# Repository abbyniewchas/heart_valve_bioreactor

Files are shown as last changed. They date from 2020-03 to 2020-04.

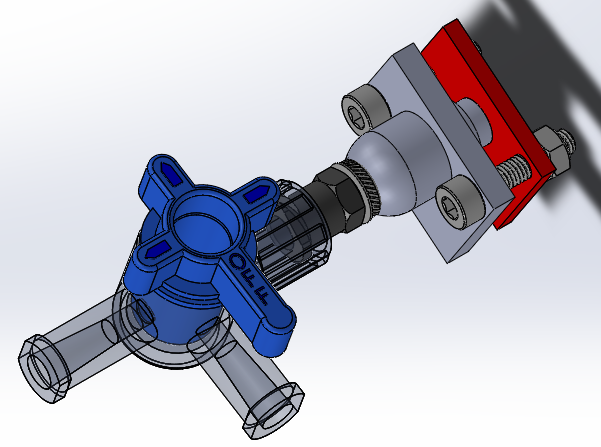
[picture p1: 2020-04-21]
designs/Pressure transducer /PressureSensorv2/Assem2.PNG

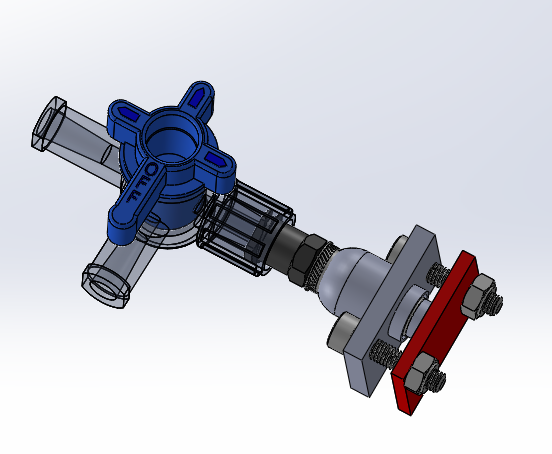
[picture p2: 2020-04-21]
designs/Pressure transducer /PressureSensorv2/Assem1.PNG

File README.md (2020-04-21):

# heart_valve_bioreactor
This github repo contains the CAD and software for our capstone's bioreactor

# Designs
The CAD for all designed components are included in this folder. Details of how to adjust the processing chamber's parameters are given in our group's capstone design report (CDR).

# Software
The software has been broken up into Arduino code and MATLAB code. The Arduino code is what runs on our system's arduino in order to run the bioreactor. The only file that should be changed in this folder is the .ino file that is actually flashed onto the Arduino board. The MATLAB folder contains files for data analysis and as well as code and simulink models that are useful for control design.

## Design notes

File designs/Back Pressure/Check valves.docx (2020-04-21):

Check valves

We need a check valve to ensure the fluid in the diaphragm pump can only exit one direction. The ideal check valve in this situation would be one with zero cracking pressure. This would mean that only a few cm of H2O would open the valve, allowing for continuous flow from the media reservoir into the diaphragm. The ideal check valve would also have zero closing pressure, so that upon contraction of the diaphragm the valve immediately closes. There are several different types of check valves, but there are three worth considering for this application.

- Swing valves
- Ball valves
- Poppet valves

These three types of valves tend to have the lowest cracking pressure available. Through research, several potential vendors were identified. The vendor CheckAll was chosen, as they produce valves with cracking pressure of 0.125psi, the lowest that could be found at a reasonable price. They also allow tunable materials so that the valve could be customized to our system.

https://www.checkall.com/PDFfiles/U3.pdf

https://www.checkall.com/PDFfiles/application_guidelines.pdf

Sizing

Going back to Cv, we want a valve that can allow for at least 5 L/min at as low of a pressure as possible. This will allow us to limit the necessary elevation of the media reservoir. CheckAll makes valves in multiple sizes, and the two that are most applicable are the ½” and ¾” sizes. These valves have Cv of 4.3 and 7.2 respectively.

Cv 4.3

Using the Cv equation, in order to get 5 L/min across this valve we would need a dP of 0.3psi or 21.6 cm H2O.

Cv 7.2

Repeating the same calculation, we would need a dP of 0.183psi or 12.9 cmH2O

These calculations lend that it would be best to go with a ¾” valve so that it is not necessary to elevate the media reservoir by nearly 22cm.

Housing Material

The three most common materials for valves are carbon steel, brass, and stainless steel. For our purposes, stainless steel is the obvious choice. Carbon steel is prone to rusting in aqueous environments, and brass’s lead content disqualifies it from use with potable water which is a solid reason not to be using it for allowing cell growth.

Seat Material

Two of the most common seat materials are BUNA-N and EDPM. BUNA is better suited for corrosive medias, oils, and hydrocarbons. EDPM is made specifically for water systems, making it the obvious choice.

½” 99.55

¾” 127.90

1” 179.15

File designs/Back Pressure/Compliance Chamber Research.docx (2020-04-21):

Rough material requirements:

1. Can withstand pressures of up to 180mmHg (3.5psi)
  - Depending on how we make the chamber this requirement will be more focused on the seams/fittings and glued surfaces rather than the material itself. Most hard plastics will withstand this pressure easily
2. Biocompatible
3. Compatible with EtO
  - https://www.industrialspec.com/resources/plastics-sterilization-compatibility/
    - Good table of different plastics and their compatibility with different sterilization methods
4. Clear (allows for visual inspection of function, accurate adjustment of volumes)
5. Reasonable price (compliance chamber should not be $1000)
  - Easily machinable or stock cylinder source would be best

Candidates:

- Acrylic/PMMA
  - https://www.ipolymer.com/pdf/Acrylic.pdf
  - https://www.acmeplastics.com/acrylic-vs-polycarbonate
  - https://www.vanderveerplastics.com/compare-materials.html?sel1=acrylic&sel2=polycarbonate
- Polycarbonate
  - https://www.ipolymer.com/pdf/Polycarbonate.pdf
  - https://www.mddionline.com/medical-applications-polycarbonate
    - Polycarb is a popular material in medicine, used in many devices and tubing
    - Stronger than acrylic, but less transparent (only slightly)
    - More expensive
    - Easier to machine (would only really make a difference if we machine it ourselves, acrylic is stiffer → easier to shatter during the machining process)

Polycarb seems to be the better fit, but either will work for our purposes

Volume Requirement

See derivation PDF

Pressure Requirement

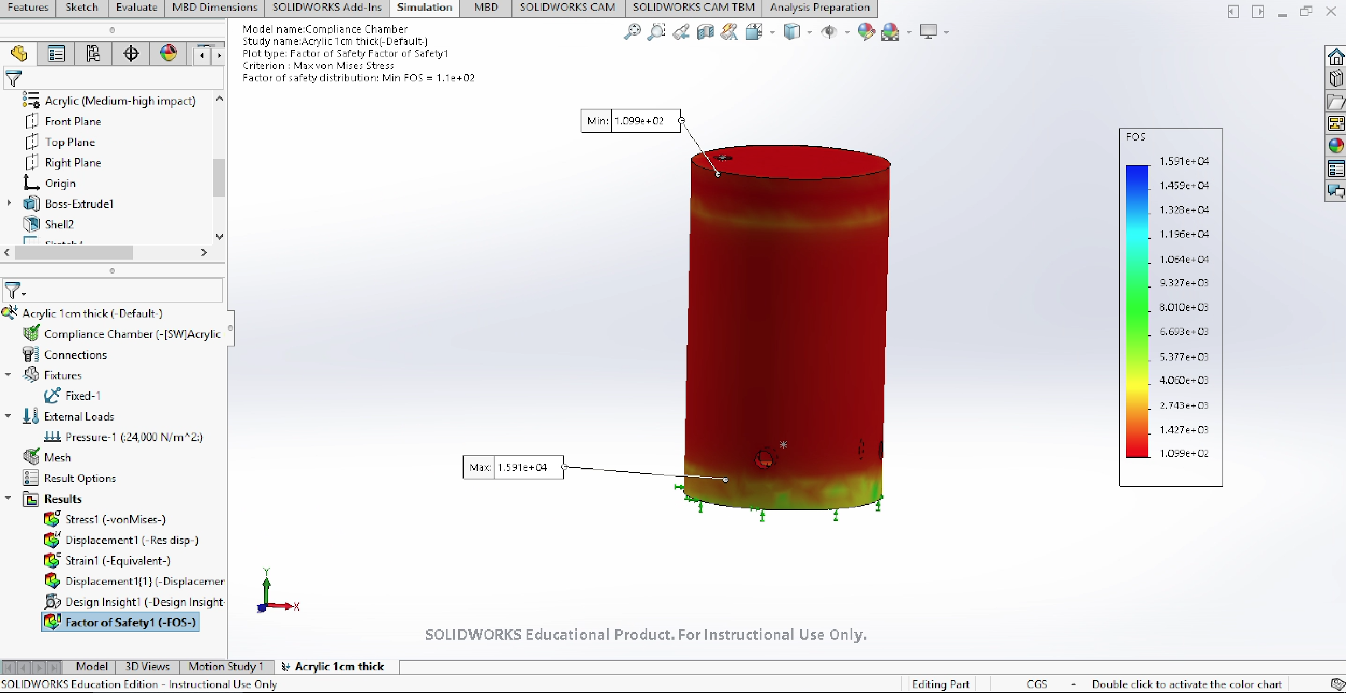
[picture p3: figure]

Solidworks simulation shows that with 1cm thick walls of Acrylic (PMMA) our factor of safety at 180mmHg would be over 100 → this is more than safe. Polycarbonate is a stronger material so this design would work for either material.

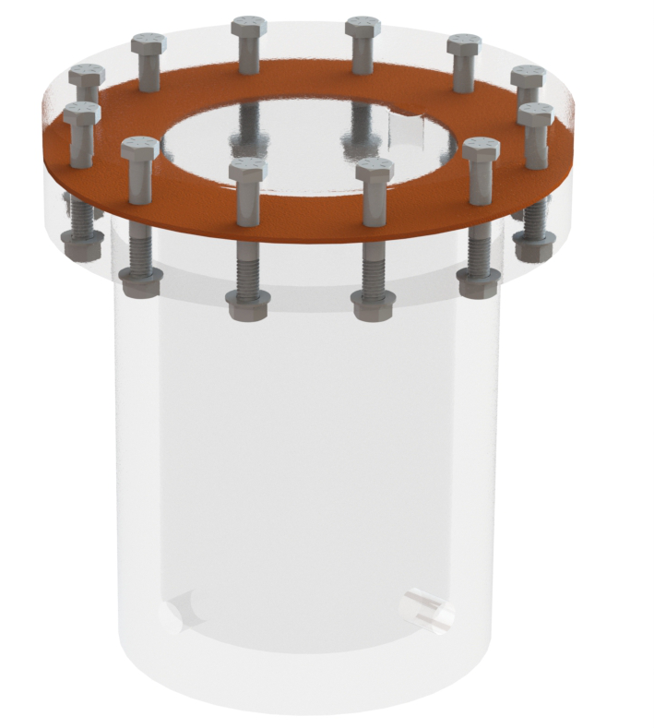
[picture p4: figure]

Next Steps

The only remaining unknown for the compliance chamber is the inlet/outlet hole sizes. These will hopefully be known soon as we decide on fitting types and tubing sizes. Finally, we need to look into designing the chamber so that it is manufacturable. The design to the right is a first pass concept featuring a machined cylinder with a flange that is sealed by a cap / rubber disk fastened with screws. While this design would work, the big cylinder/flange piece is not very manufacturable

Design update:

Having a three way valve connected to a single inlet on the bottom of the compliance chamber would be the way to go.

Manufacturing

Contracting

- Most straightforward choice of manufacturing method is CNC. Plenty of companies do CNC machining in both acrylic and polycarbonate
- One quote was fucking 3500$$$
- Need to modify the current design if we are going to contract it
  - Large cylinder piece with the flange is not very manufacturable. CNC starts with a block of material, machining that cylinder means a ton of material is needed

Stock acrylic + acrylic cement

- Can change design to just a cylinder with two caps, buy stock acrylic from mcmaster
  - https://www.mcmaster.com/acrylic
- Probably use some type of resin to join them
  - Weld-on 4
  - https://www.gogsg.com/ASSETS/DOCUMENTS/ITEMS/EN/ips4-04_spec.pdf
- Drill holes and tap them ourselves where necessary
- Maybe 200$, leaves room for messing up

Dimensions + links for parts we would order to build it

Systemic

  - 4” ID, 5.82 - 6” height
  - ~~8486K575~~ (https://www.mcmaster.com/8486K575) ~~main walls~~
  - ~~1221T95~~ (https://www.mcmaster.com/1221T95) ~~bottom disc~~
  - ~~1221T39~~ (https://www.mcmaster.com/1221T39) ~~2x Top discs~~
- Pulmonary
  - 5” ID, 8.75-9.32” height
  - 8486K585 (https://www.mcmaster.com/8486K585) main walls
  - 8581K37 (https://www.mcmaster.com/8581K37) bottom disc
  - ~~https://www.mcmaster.com/8581K39~~ ~~2x Top discs~~
- For the top and bottom / flange components, you would get a cast acrylic SHEET and just laser cut it. Noah has a ton of acrylic stock we can use so don’t buy yet
- Weld-on 4
  - https://www.amazon.com/Weldon-Applicator-Bottle-Pint-10308/dp/B00TCUJ7A8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
  - https://www.gogsg.com/ASSETS/DOCUMENTS/ITEMS/EN/ips4-04_spec.pdf
  - https://www.gogsg.com/ASSETS/DOCUMENTS/ITEMS/EN/IPS4-01_MSDS.pdf

Blown glass?

- nah

Pressure Release Valve

- Should release pressure once pressure in compliance chamber exceeds 3.5 psi
- Possible products
  - 4703K54 (https://www.mcmaster.com/4703K54)
  - 48935K25 (https://www.mcmaster.com/48935K25) (cheapest, smallest)
  - 7844K52 (https://www.mcmaster.com/7844K52)

O-Rings

Literature

- Parker O-Ring Handbook (https://www.parker.com/Literature/O-Ring%20Division%20Literature/ORD%205700.pdf)
  - Groove dimensions for a face seal:page 4-18
  - Compression force required: Figures 2-4 through 2-8 in Section II

Products

- https://www.mcmaster.com/o-rings
- #254 should work 9452K355 (https://www.mcmaster.com/9452K355)
- Also 161
  - .077 +/- .003” depth X 0.122 +/- .002” width
- 51
  - .052 +/- .002” depth X .086 +/- .002” width

Manufacturing feedback from Noah

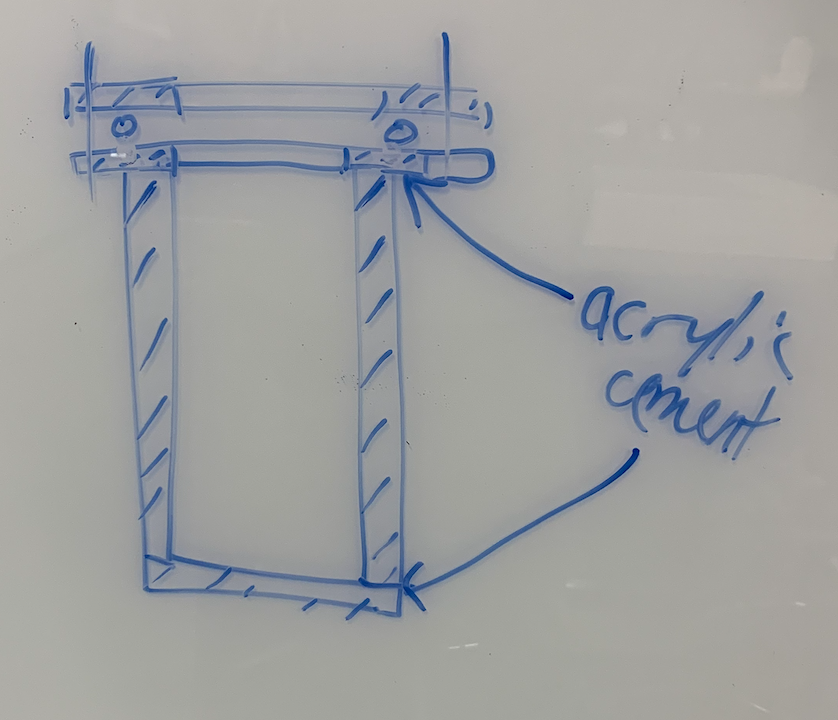
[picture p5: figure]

Design 1

- For the top and bottoms, get CAST acrylic SHEETS
- Cast acrylic is easier to machine, laser cutting works on either cast or extruded
- For the O-ring groove you would use laser cutting and engrave it. Would take some trial and error to get the correct specs for the O-ring
- Profile of flange + screw holes are easy to laser cut

Design 2

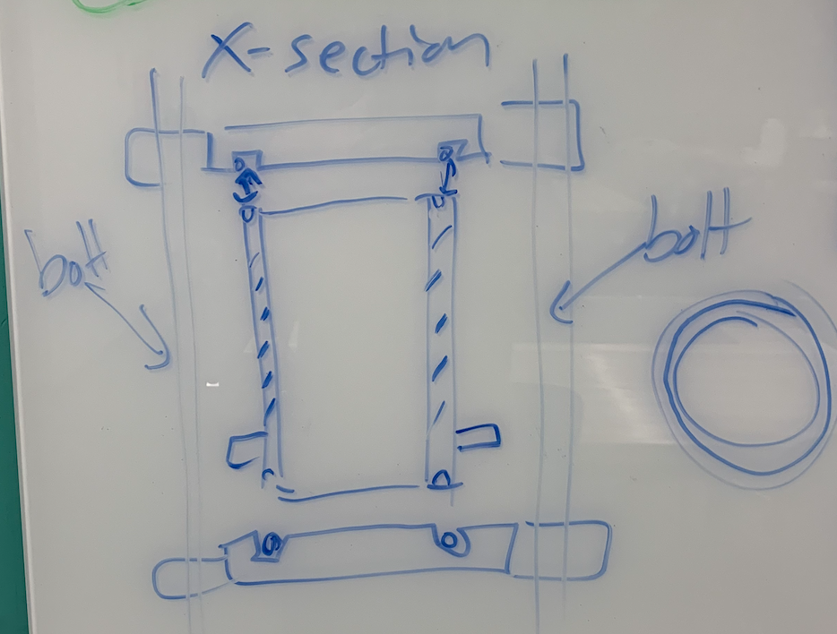
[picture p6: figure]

- I asked noah if he could put a groove on the top and bottom of the tube itself if the tube was thick enough
  - He said with a lathe it is doable

Confirmed redesign:

- Top and bottom pieces
  - Cast acrylic sheet
    - 8560K266 (https://www.mcmaster.com/8560K266)
  - One inlet each
  - O-ring groove on each
    - O ring dimensions must match with tubing dimensions such that the tube edges form one face of the seal
    - 9557K142 (https://www.mcmaster.com/9557K142)
      - EPDM
- Walls
  - 8486K585 (https://www.mcmaster.com/8486K585) main walls
- RODS
  - 10” long, ¼”-20 stainless steel 316
  - McMaster: https://www.mcmaster.com/90575A224
- Cutter for machining as requested by Noah
  - https://www.sparkfun.com/products/14853
- Waste board for machining as requested by Noah
  - https://www.sparkfun.com/products/14904

Other cost-effective tank designs

https://www.usplastic.com/catalog/item.aspx?itemid=134241&catid=835

Notes:

EDPM is biocompatible, has excellent swell resistance, therefore we select the smaller gas and vacuum groove width from the o-ring handbook.

Delrin is biocompatible

‘

Material compatibility charts for funsies: https://www.calpaclab.com/acetal-polyoxymethylene-chemical-compatibility-chart/#

Info about durometer:

https://promo.parker.com/promotionsite/oring-ehandbook/us/en/ehome/Hardness

Info about EDPM being used in medical applications: https://www.aceseal.com/o-ring-materials

Biocompatibility of delrin: https://onlinelibrary.wiley.com/doi/abs/10.1002/jbm.820190505

List of biocompatible plastics: https://www.google.com/imgres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 (https://www.google.com/imgres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)

Fittings:

Bottom T-connector: ½” NPT, ½” pipe diameter, barb, made out of acetal (same as Delrin)

https://www.mcmaster.com/5047K61

Top T-connector:

Nuts:

¼”-20 Flange nut: https://www.mcmaster.com/94842A101

¼”-20 Cap nut: https://www.mcmaster.com/98858A101

Male Luer-Male ¼” NPT adapter: https://www.mcmaster.com/51525K437

½” NPT Stopcock: https://www.mcmaster.com/4793K844

TO DO:

1. Determine fittings for pressure relief and stopcock at the top of the compliance chamber
2. Determine torque spec and buy torque wrench
3. Pat ourselves on the back
4. Have a pint

Torque Specification

Directions: https://www.darcoid.com/userfiles/cms/subpage/files/31/Installation.pdf

Part 1: Calculate compressive load required for face seal o-ring application

https://www.parker.com/literature/O-Ring%20Division%20Literature/O-Ring%20ehandbook%20pdfs/compression%20load%20force%20by%20cross%20section%2070%20and%2090%20duro.p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

Squeeze is 19-32%, the midpoint is ~25%

This is the ratio of deformation to the thickness of the o-ring.

Referring to the chart above, 25% squeeze results in 25 lbs per inch of o-ring circumference of compressive load.

Part 2: Calculate necessary bolt torque and spacing for the face seal

https://mechanicalc.com/reference/bolted-joint-analysis

1. STOPCOCK/PRESSURE RELIEF FITTINGS

Sterile Pressure Relief

→ NPT to Female Luer Adapter: (https://www.mcmaster.com/51525K437)https://www.mcmaster.com/51525K437

→ Luer Male to Luer Female On/Off Valve: (https://www.mcmaster.com/7033t24)https://www.mcmaster.com/7033t24

→ Male Luer Filter: Sterifix 0.2 μm; B. Braun Melsungen AG, Germany (we already have these)

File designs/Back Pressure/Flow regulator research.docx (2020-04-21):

[1]https://www.cedengineering.com/userfiles/Control%20Valves%20Basics%20-%20Sizing%20&%20Selection.pdf

Ball Valves

- high recovery valves, having a low pressure drop and relatively high flow capacity.
- Usually open or closed, limited throttling
  - Not what we want

Butterfly Valves

- Minimal pressure drop when fully open (good for us)
- Limited throttling

Globe Valves

- Precise flow regulation, but design introduces lots of turbulence to flow even when fully open
  - This means an open valve would still have a decent amount of resistance
- Wide throttling
- Needle valves are in this category

Gate Valves

- Best for open/closed
- Best for infrequent operation, good sealing

Types of actuators:

Pneumatic, electronic, manual

- Electronic has superior precision, fastest response time
- Mechanical has same range of regulation but with much longer timescale of adjustment (also much cheaper)

Types of regulators:

- Fixed orifice flow regulators
  - needle/globe valve, select a constant orifice size
- Pressure compensating flow regulators
  - Include a spring to retain constant flow rate despite pressure changes

General guidelines: Valves should be sized so that maximum flow is obtained at about 90% valve open. Valves should be able to provide normal flow conditions at around 60% to 70% of the travel. Valve should provide minimum flow when about 10% open [1].

Flow Coefficient Cv:

- Cv = amount of flow in gpm that will flow through the valve when it is 100% open with a pressure differential of 1 psi (S is specific gravity, which is 1 for our purposes)
  - Our max pressure differential across the valve is going to be 180mmhg (3.5psi) according to our requirements, but typically it will be 120 (2.3psi)
  - Our max flow will be around 5L/min = 1.32gpm
  - So we want at a pressure difference of 2.3psi across an open regulator to allow 1.32gpm of flow
    - Cv = 1.32gpm / sqrt(2.3psi) = 0.87
  - But really pulmonary pressures are the limiting case. Cv of 0.87 → no way we will get 5L/min at a pressure drop of 20mmHg across the regulator.
    - We need 5 L/min with 20mmHg (.38psi) drop across the valve
    - Cv = 1.32gpm / sqrt(.38psi) = 2.14
    - We want normal flow (5L/min) when the valve is ~60% open, so a Cv closer to 3 would probably be fine

https://www.globalspec.com/industrial-directory/electronic_air_flow_control_valve#articles

Viable Options
Mechanical | https://www.mcmaster.com/45585k78 (Cv = 2.67) - can connect to tubing of ¾” OD https://www.mcmaster.com/1042k21 (Cv = 2.47) 1042K36 (https://www.mcmaster.com/1042K36)
Electronic | https://www.omega.com/en-us/valves-pumps-and-mixers/valves/proportional-valves/pv14/p/PV12-B (Cv = 3.5)

How necessary is an automatic valve?

- Main purpose: augment the function of the pump to have finer control over pressure waveform
  - It would primarily augment the pressure curve after the pump “contraction” is finished, assuming the pump is capable of generating the initial curve

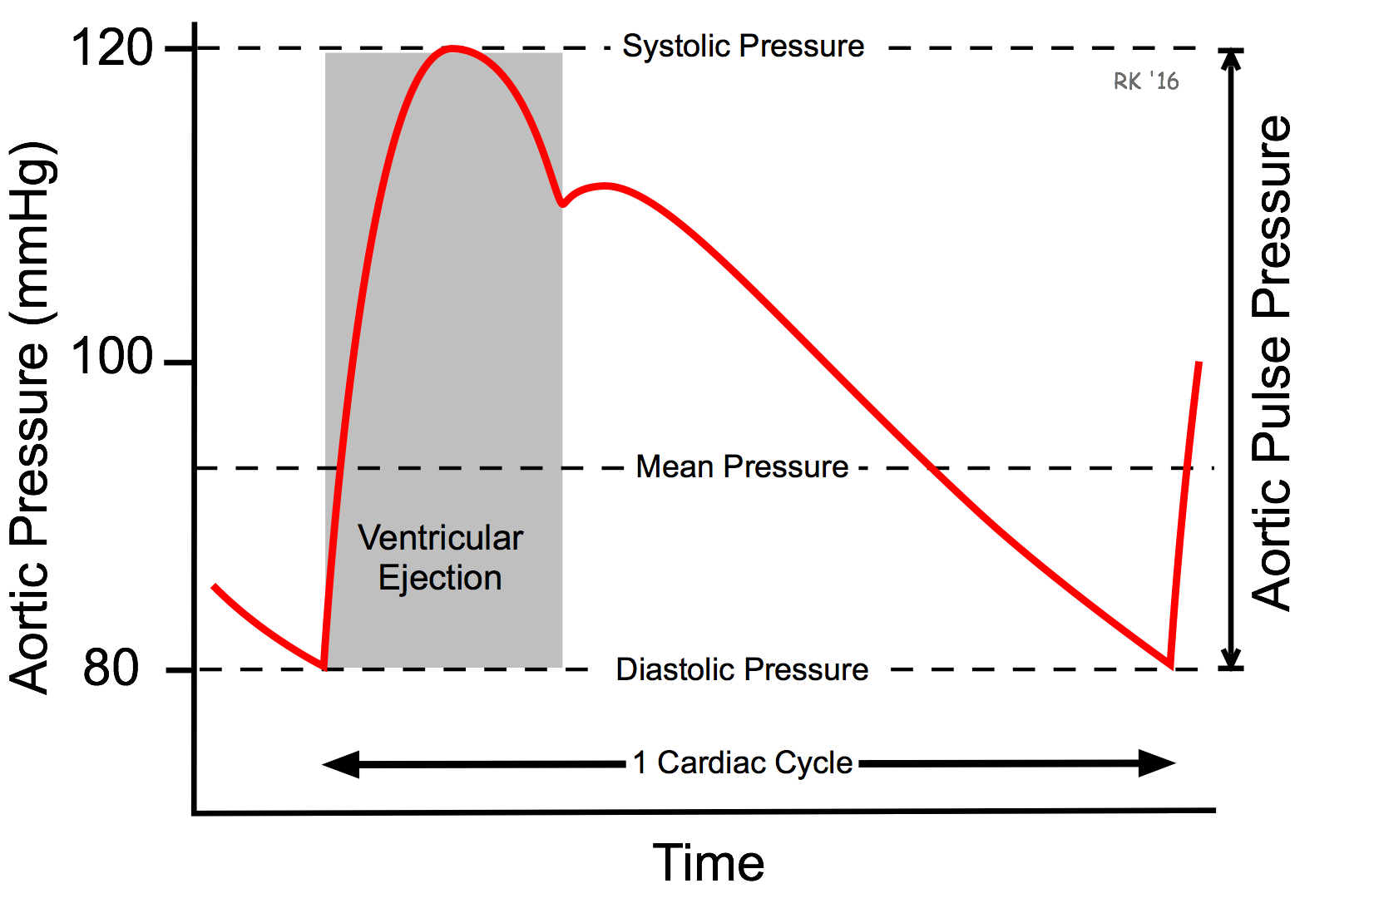
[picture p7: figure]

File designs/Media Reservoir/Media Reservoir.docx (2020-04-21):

Media Reservoir

Components

Filter

- The aortic chamber fluid outlets were connected by silicone tubing to an air-tight pressurizing reservoir (compliance chamber), which in turn was connected to a second reservoir exposed to atmospheric air via one top outlet fitted with a 0.22 μm air filter. (https://www.ncbi.nlm.nih.gov/pmc/articles/PMC3039844/#!po=12.5000)
- Sterile filters (Sterifix 0.2 μm; B. Braun Melsungen AG, Germany) were interposed at the top of the medium reservoir to avoid contamination during oxygenation of the circulating medium. (https://pdfs.semanticscholar.org/cb62/8044a4c4445836e1689b58cf9297ad36c74d.pdf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)
- 0.22 vs 0.45 https://journal.pda.org/content/50/3/147

Container

- Volume? Calculate…
- Material? Sterilizable, biocompatible, hemocompatible

Emptying

- Luer lock port
- To stop-cock
- To removal sterile luer lock filter

All ports need to be sterile, mixing (inlet from top? - research mixing and gas perfusion), find a paper for mixing necessity for gas perfusion in mammalian cells (specifically heart valves)

Fittings

Media Reservoir Media Exchange Ports

→ ¼” NPT to Luer socket (https://www.mcmaster.com/9198T18)https://www.mcmaster.com/9198T18

→ ¼” Luer plug to barb (https://www.mcmaster.com/9198T16)https://www.mcmaster.com/9198T16

Ø One line goes to the system

Ø Switch the lines to add media

Ø Don’t connect a media bag at the other end and it will drain.

Ø Also could use Luer Male to Luer Female On/Off Valve with an in-line luer filter: (https://www.mcmaster.com/7033t24)https://www.mcmaster.com/7033t24

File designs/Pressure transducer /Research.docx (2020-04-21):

https://www.reddit.com/r/arduino/comments/67x9zy/4wire_pressure_transducer_wiring/

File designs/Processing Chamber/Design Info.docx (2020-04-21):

Machining top and bottom piece:

-Protolabs SLA 3D printer

-Watershed material that will be custom finished to be clear

-Prints with a tolerance of 0.05mm

https://www.designworldonline.com/biocompatible-material-fits-medical-design-requirements/

https://www.fostercomp.com/stewardship/usp-class-vi/

Application of Watershed:

WaterShed XC 11122 offers many properties that mimic traditional engineering plastics including ABS and PBT. This makes the material ideal for many applications in the automotive, medical and consumer electronics markets and include:

- Lenses

- Packaging

- Water flow analysis

Fittings:

-CHECK TAPS

Screws/Bolts:

-3in long, ¼ by 20 threading

https://www.mcmaster.com/85555a113

https://www.mcmaster.com/95462a029

https://www.mcmaster.com/92196a801

O-rings:

-O-ring EPDM 029

Aortic Root Info:

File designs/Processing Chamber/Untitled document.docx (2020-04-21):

How to Update Processing Chamber SolidWorks Files

The processing chamber will need to be updated to reflect the dimensions of the hydrogel heart valve. The current model is for the mechanical heart valve that was being tested.

1. Top of the Processing Chamber
  1.1. The first important thing to note is that 10 different SolidWorks files were created for valves ranging from 10-30mm in increments of 2mm. The file name doesn’t necessarily correlate with the same size of the valve that is being created. For instance, the title “TopChamber_24mm” refers to the opening diameter of the aortic root. This diameter is actually the outer diameter of where the leaflets are inserted, highlighted in Figure 1 as “Outer Leaflet Diameter”. This will change depending on the dimensions of the heart valve.

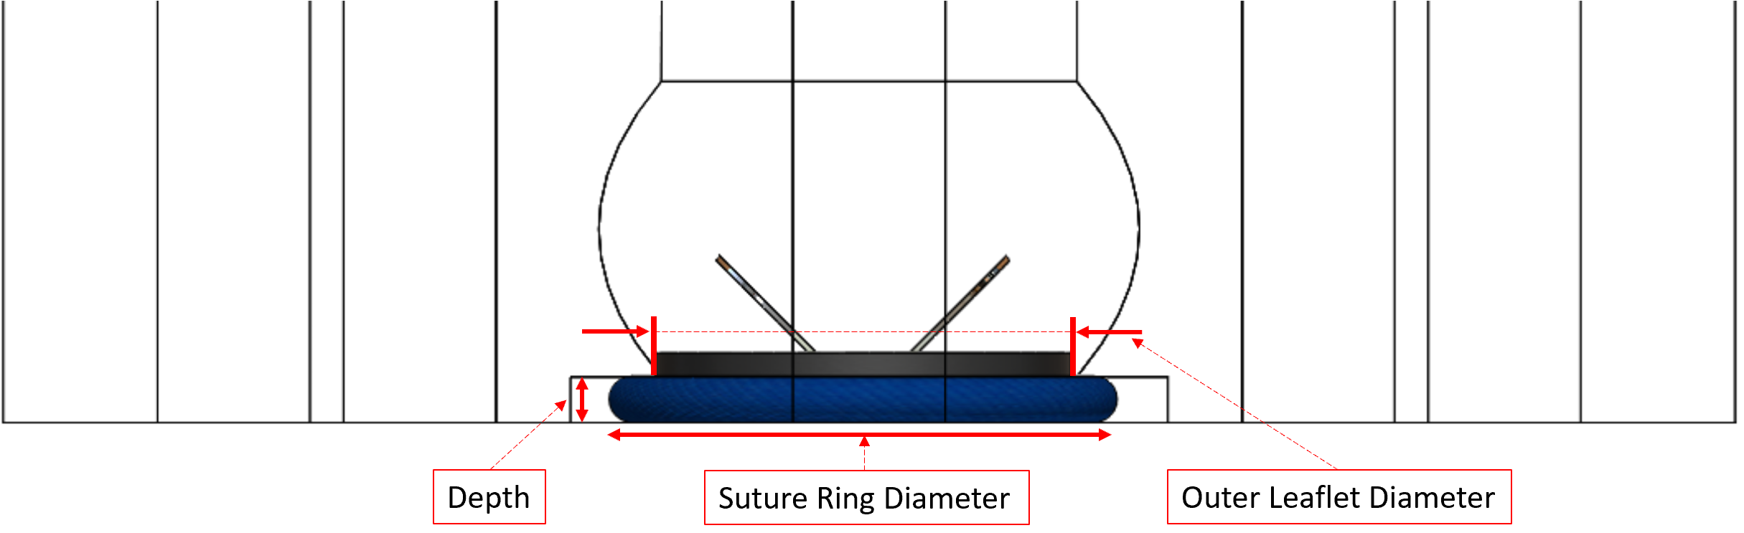
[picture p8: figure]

Figure 1

  1.2. The mechanical valve that we were given was a size 22. It had an inner diameter of 20mm, an outer leaflet diameter of 24mm, an outer suture ring compression diameter of about 32mm and a suture ring depth of 3.15mm. The heart valve is clamped in place by the suture ring. The dimensions are shown below.

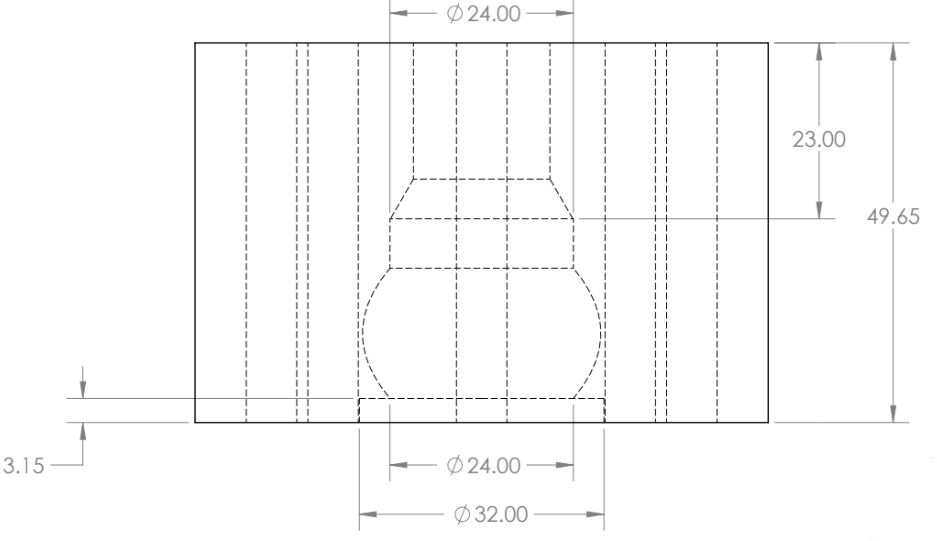
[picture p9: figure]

Figure 2

  1.3. The dimensions will need to be edited in the SolidWorks tree.The SolidWorks tree is shown in Figure 3. The key dimensions are the “Outer Leaflet Diameter” and “Depth”. Most likely, the NPT Hole, Aortic Root, Ascending Aorta, and Bolts Holes will not need to be changed, as they do not specifically hold the heart valve in place.

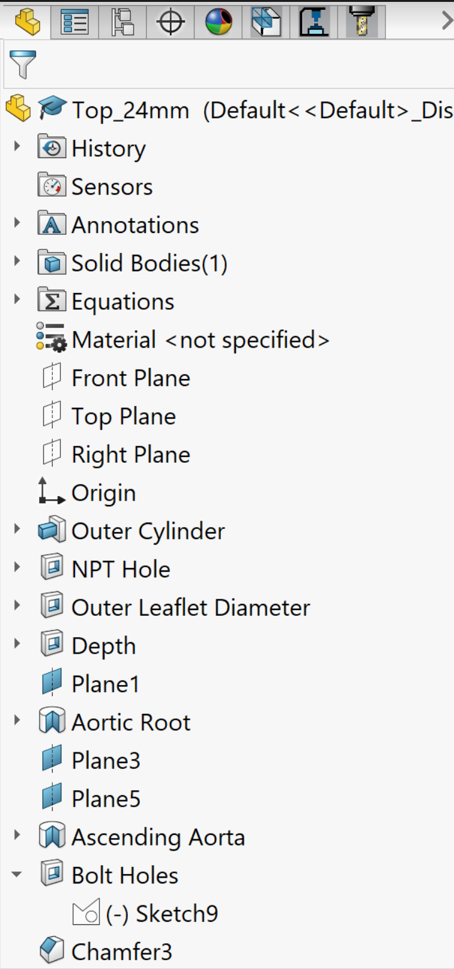
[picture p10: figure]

Figure 3

  1.4. One of the dimensions that will most likely need to be changed is the diameter of the outer leaflet diameter. As mentioned earlier, the SolidWorks file is named in reference to this diameter. The Top_24mm means that the outer leaflet diameter is 24mm. All of the aortic root dimensions are tied to the outer leaflet diameter through equations, shown in Figure 4. The equations are shown in Figure 4. The aortic root opening is the same diameter as the outer leaflet diameter “A”; in the SolidWorks model this is shown as “D2@Sketch6” and the equation is A/2, because it is a cut revolve so only half of the outline was drawn and then revolved around the centerline.. The diameter where the aortic root opens into the ascending aorta is also the same diameter as “A”; in the SolidWorks model this is shown as “D3@Sketch” and the equation is A/2, because it is a cut revolve so only half of the outline was drawn and then revolved around the centerline. The height of the aortic root .71x the outer leaflet diameter size “A”, and is called “Aortic Root Height” in global variables. The maximum diameter of the aortic root occurs at half the aortic root height and is called “Max Diameter Height” in global variables. The maximum diameter of the aortic root is 1.3x larger than the outer leaflet diameter and is shown as “Max Diameter” in the global variables; to reiterate the aortic root was created using a revolve cut which is why the equation shows A*0.65 (half of 1.3). Every time the outer leaflet diameter is adjusted, these values automatically adjust with it.

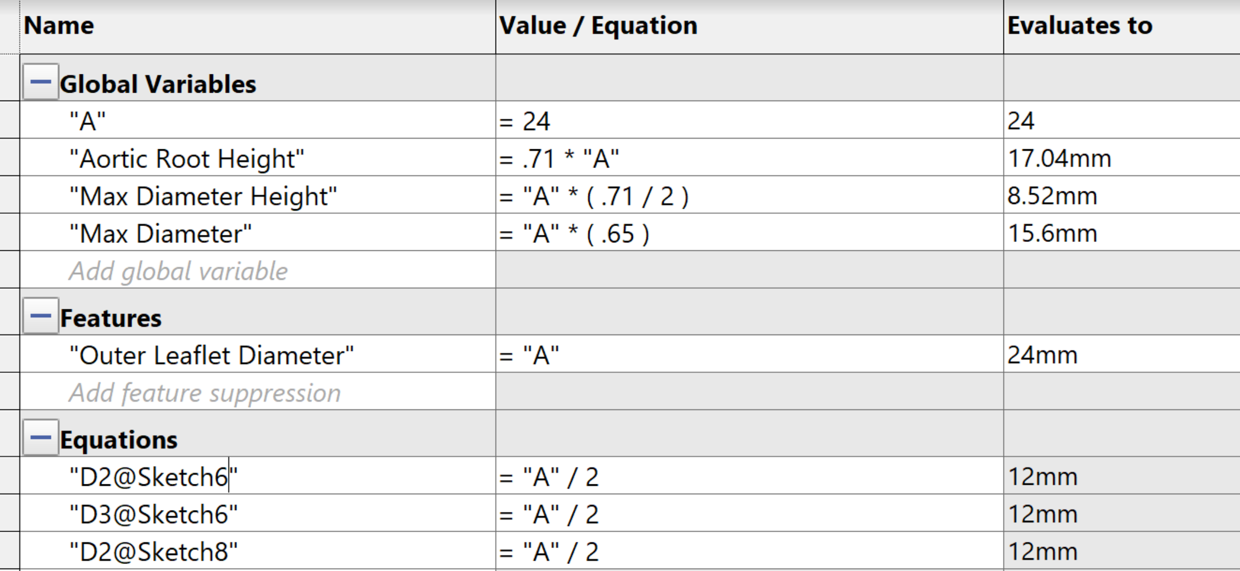
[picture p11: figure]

Figure 4: Aortic Root Equations

  1.5. For the hydrogel heart valve, the dimensions for holding it in place will need to be changed. The rigid ring of the valve needs to be held firmly in place throughout testing. To ensure this happens the cut extrude of depth will need to be changed to match whatever the depth of the suture ring being used is. Also, the diameter of the depth will need to be changed to ensure it is wider than the width of the compressed suture ring. In our SolidWorks model an extra 2mm was added to this depth diameter, to ensure that the fabric on the ring will not be clamped outside of its designated cutout. Lastly, the outer leaflet diameter will have to be adjusted to whatever the diameter is of the portion of the valve extruding into the aortic root.
2. Bottom of the Processing Chamber
  2.1. The bottom of the processing chamber is a cylinder with a flat face that mates with the top of the processing chamber to hold the heart valve in place. The two key dimensions of the bottom of the processing chamber are the inlet flow diameter and o-ring groove (Figure 5).

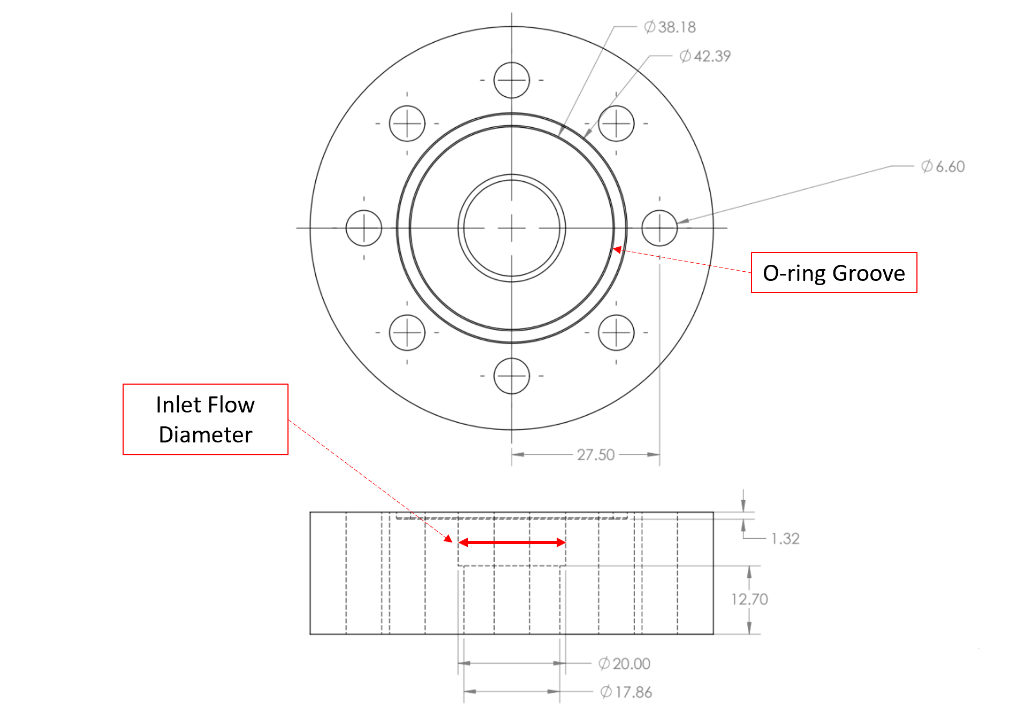
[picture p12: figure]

Figure 5: Bottom Chamber Diagram

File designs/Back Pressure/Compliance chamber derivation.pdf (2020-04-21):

The goal of this mathematical model is to derive the needed volume of the compliance chamber to accommodate physiological compliances. In other words, we want to know the total volume of air in the compliance chamber when there is only atmospheric pressure.

Compliance (C) is defined as a change in volume for a given change in pressure. In the physiological context, dV and dP will always be the same sign, as an increase in vascular pressure leads to an increase in volume of the vessel and vice versa. In our compliance chamber it is the opposite, as an increase in pressure results in a reduction of the volume of air in the chamber. As such there is a negative sign in the equation.

[1] C = −

∆V
∆P

wℎere ∆V = V2 − V1 and ∆P = P2 − P1

Additionally, we want to assume that there will be isothermal compression and expansion, which yields the second equation.

[2] V1P1 = V2P2

Rearranging equation [1] to solve for V2:

[3] V2 = V1 − C∆P

Substituting V2 from equation [3] into equation [2] and solving for V1:

V1 =

P2
P1

(V1 − C∆P)

V1 =

P2
P1

V1 −

P2
P1

C∆P

V1 (1 −

P2
P1

) = −

P2
P1

C∆P

V1 =

−

P2
P1

C∆P

(1 −

P2
P1

)

Multiply by -P1/-P1

V1 =

C∆P ∗ P2
P2 − P1
[4] V1 = C ∗ P2

The limiting case would be the case of highest compliance, as the air would be compressing the most for a given change in pressure. For this we use the pulmonary compliance value of
C = 2.6 ∗ 10⁻⁸ m5
N

i and
P2 = peak pulmonary pressure + atmospheric pressure = 20 mmhg + 760 mmHg = 780 mmHg = 103991.16 Pa

Plug into equation [4] to get

V1 = 2730 mL

Therefore, we need approximately 2.7 L of air in the compliance chamber for it to behave similarly to vessels in terms of the amount of back pressure it will generate for a given stroke volume. This value doesn’t need to be exact as we will also be able to control the pump and the fluidic resistor, but I believe this is a solid rationale for having the compliance chamber be in the realm of 2.7 L in size. Doing the same calculations with the minimum systemic compliance (systemic compliance is not always constant) yields a volume of approximately 1L. This would be accomplished by raising the water level in the compliance chamber until there is only ~1L of air.

Accounting for the fact that we will have fittings into and out of the compliance chamber which will always be submerged, the actual volume of the chamber will be closer to 3L.

i B. Knierbein, H. Reul, R. Eilers, M. Lange, R. Kaufmann, and G. Rau, “Compact mock loops of the systemic and pulmonary circulation for blood pump testing,” Int. J. Artif. Organs, vol. 15, no. 1, pp. 40–48, 1992.

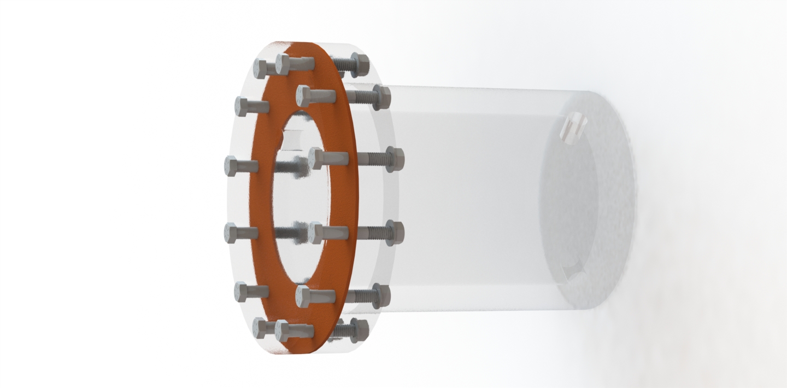
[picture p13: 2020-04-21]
designs/Back Pressure/Renders/Compliance chamber render.JPG

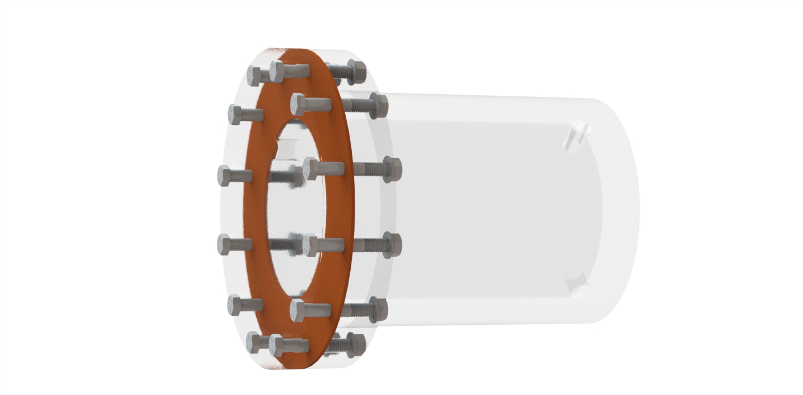
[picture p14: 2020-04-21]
designs/Back Pressure/Renders/Compliance chamber render 2.JPG

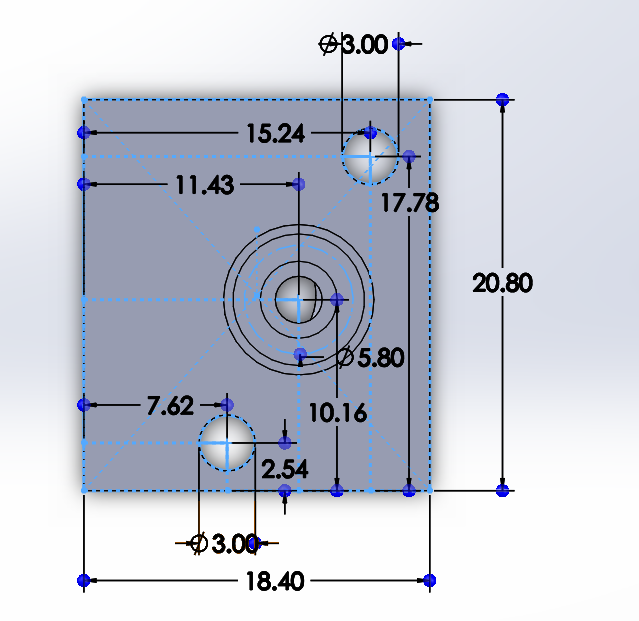
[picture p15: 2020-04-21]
designs/Pressure transducer /ForceSensorBoardDims.PNG

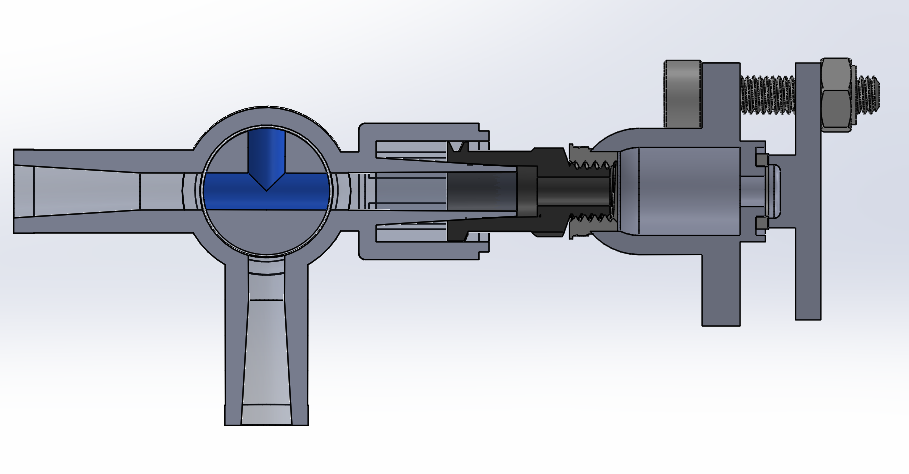
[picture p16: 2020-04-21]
designs/Full System CAD/Pressure Sensor V2/Assem3Split.PNG

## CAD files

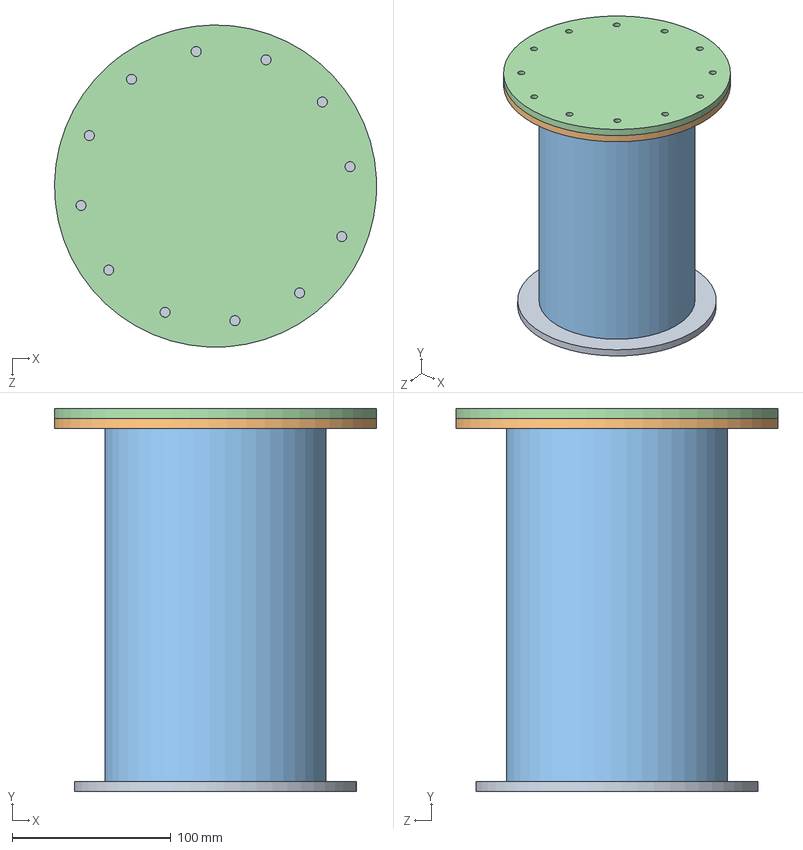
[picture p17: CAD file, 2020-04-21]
designs/Back Pressure/Solidworks/Compliance chamber assembly.SLDASM
203.1 x 241.6 x 203.1 mm
Bottom cap
Flange
Main body
Top Cap
McMaster O-RING #254

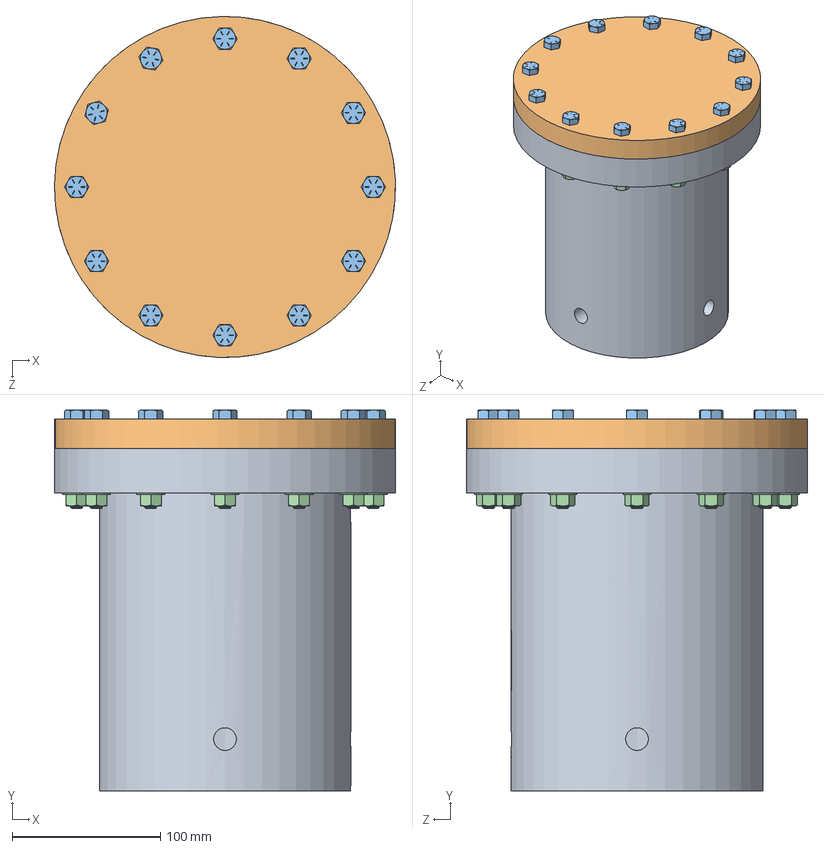
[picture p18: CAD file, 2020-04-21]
designs/Full System CAD/Compliance Chamber/Initial simulation mock-up/Compliance chamber assembled.SLDASM
230.0 x 256.9 x 230.0 mm
Compliance Chamber
Compliance Chamber Cap
screw x 12
nut x 12

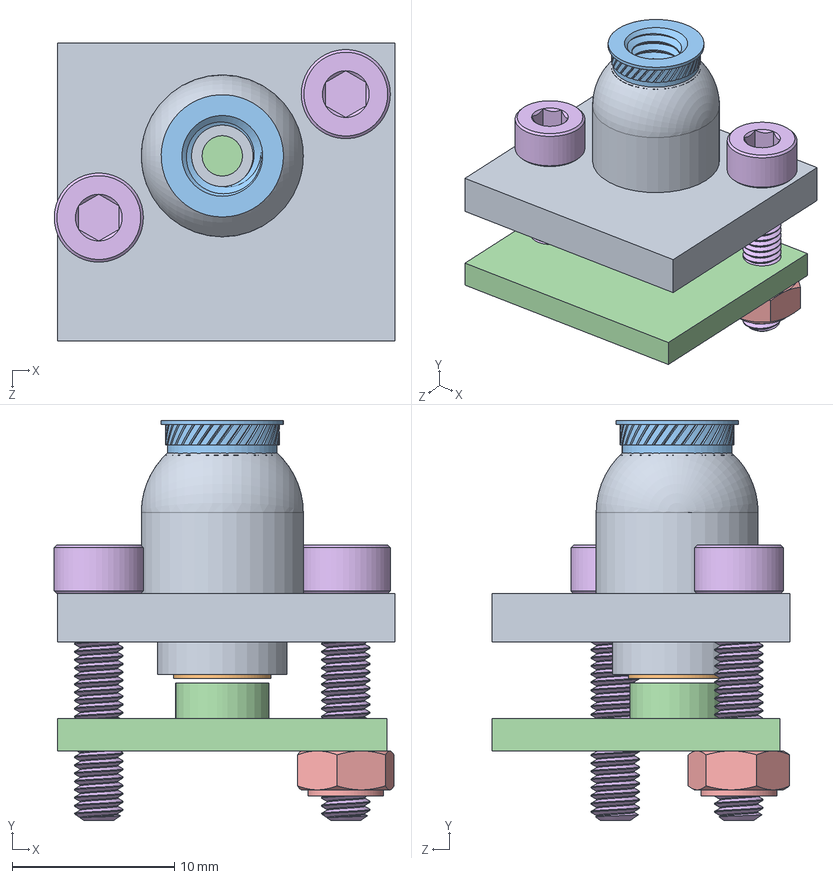
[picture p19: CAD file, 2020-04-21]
designs/Full System CAD/Pressure Sensor V2/ForceSensorAssemv2.SLDASM
21.0 x 24.7 x 18.4 mm
Capsulev2
1171N116_SQUARE-PROFILE O-RING
93365A240_HEAT-SET INSERTS FOR PLASTICS
PressureSensor
90592A085_STEEL HEX NUT
91274A106_COATED ALLOY STEEL SOCKET HEAD CAP SCREW x 2

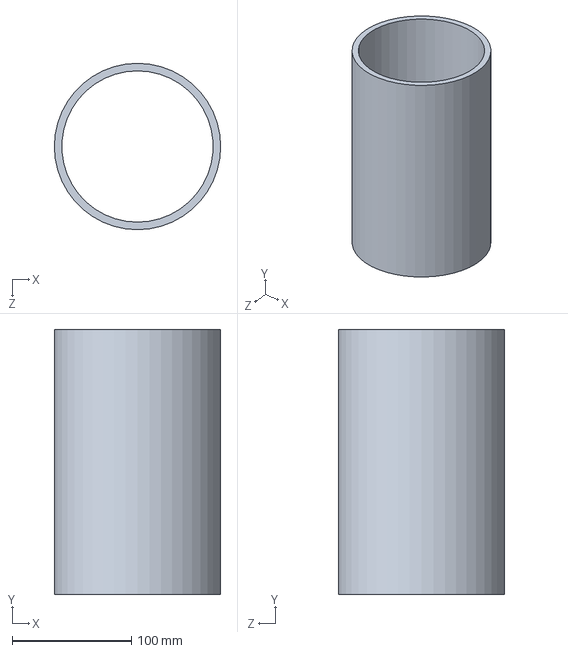
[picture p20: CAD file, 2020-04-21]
designs/Full System CAD/Compliance Chamber/CAD/Initial Design/Main body.SLDPRT
139.7 x 222.5 x 139.7 mm

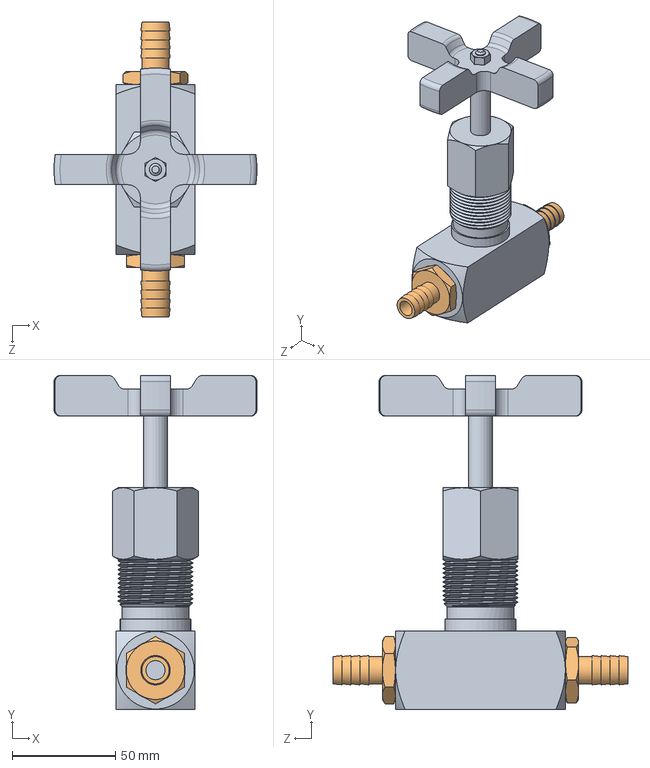
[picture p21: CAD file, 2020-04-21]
designs/Full System CAD/Frame/Flow regulator with fittings.SLDASM
98.4 x 161.9 x 142.8 mm
Flow regulator
three quarter NPT to half in tube x 2

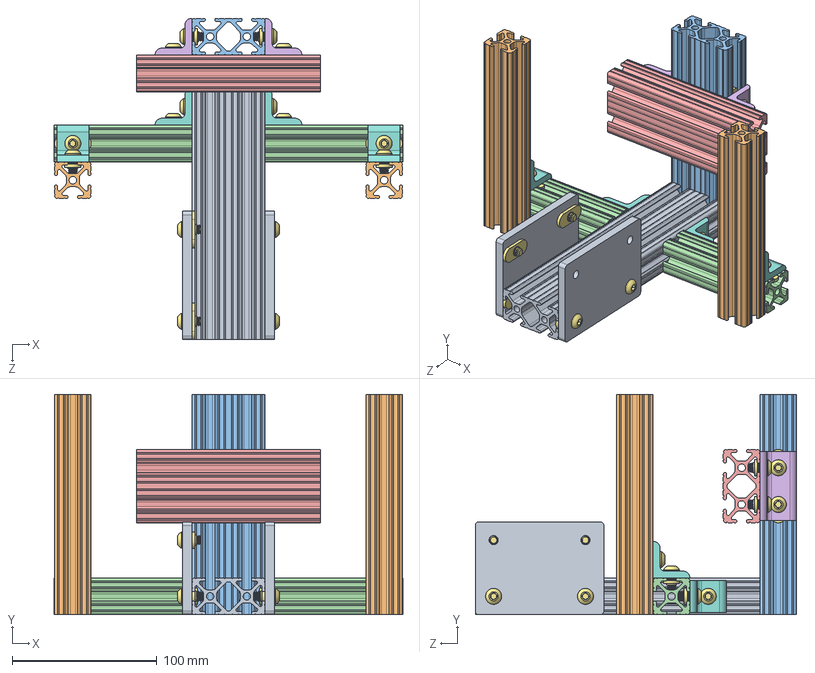
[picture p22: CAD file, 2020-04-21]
designs/Full System CAD/Pump redesign concept/Membrane Mount for redesign.SLDASM
241.3 x 152.4 x 222.2 mm
47065T418_ALUMINUM T-SLOTTED FRAMING EXTRUSION
47065T411_ALUMINUM T-SLOTTED FRAMING EXTRUSION x 2
80_20 double 6in
80_20 3.75in x 2
80_20 double 5in
80_20 L bracket wide x 2
80_20 fastening screw x 22
80_20 L-bracket small x 4
pump acrylic aligner x 2

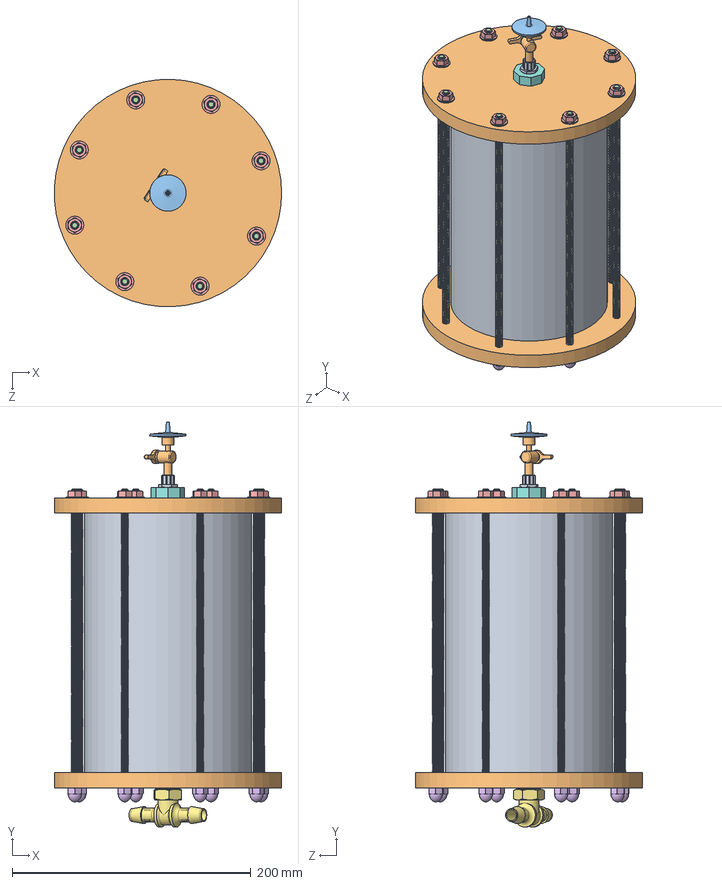
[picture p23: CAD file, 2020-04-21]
designs/Full System CAD/Compliance Chamber/CAD/FINAL DESIGN/Compliance chamber assembly.SLDASM
190.4 x 339.3 x 190.4 mm
Main body
Top + bottom of CC x 2
9557K142_STEAM-RESISTANT EPDM O-RING x 2
316 SS THREADED ROD x 8
94612A101_ZINC PLATED GRADE 8 STEEL FLANGE NUT x 8
91855A520_18-8 STAINLESS STEEL CAP NUT x 8
CC Bottom tee fitting
4880K343_1-2NPTmale-to-1-4NPTfemale
51525K437_1-4NPT-to-Luer
Stopcock (from grabcad)
Sterile filter

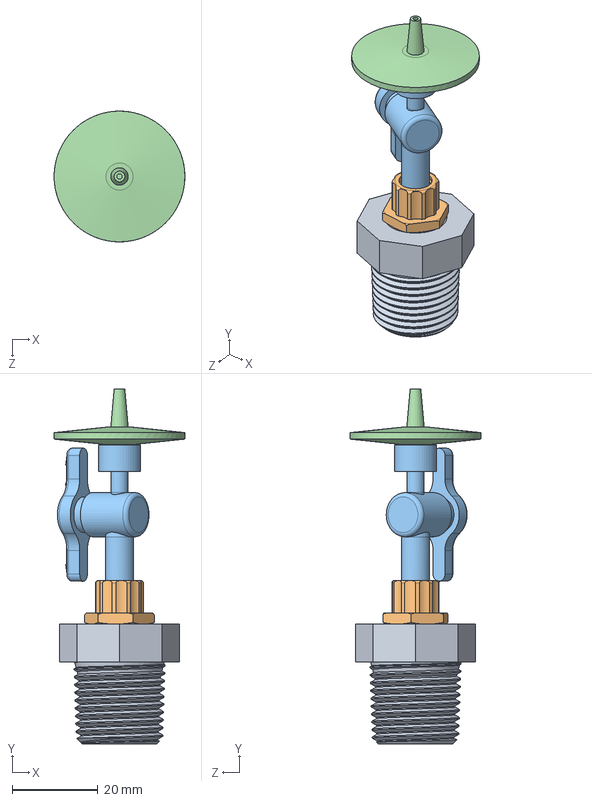
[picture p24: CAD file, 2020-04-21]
designs/Full System CAD/Tubing and fittings/Media Reservoir top fitting.SLDASM
30.5 x 82.7 x 30.5 mm
4880K343_1-2NPTmale-to-1-4NPTfemale
51525K437_1-4NPT-to-Luer
Stopcock (from grabcad)
Sterile filter

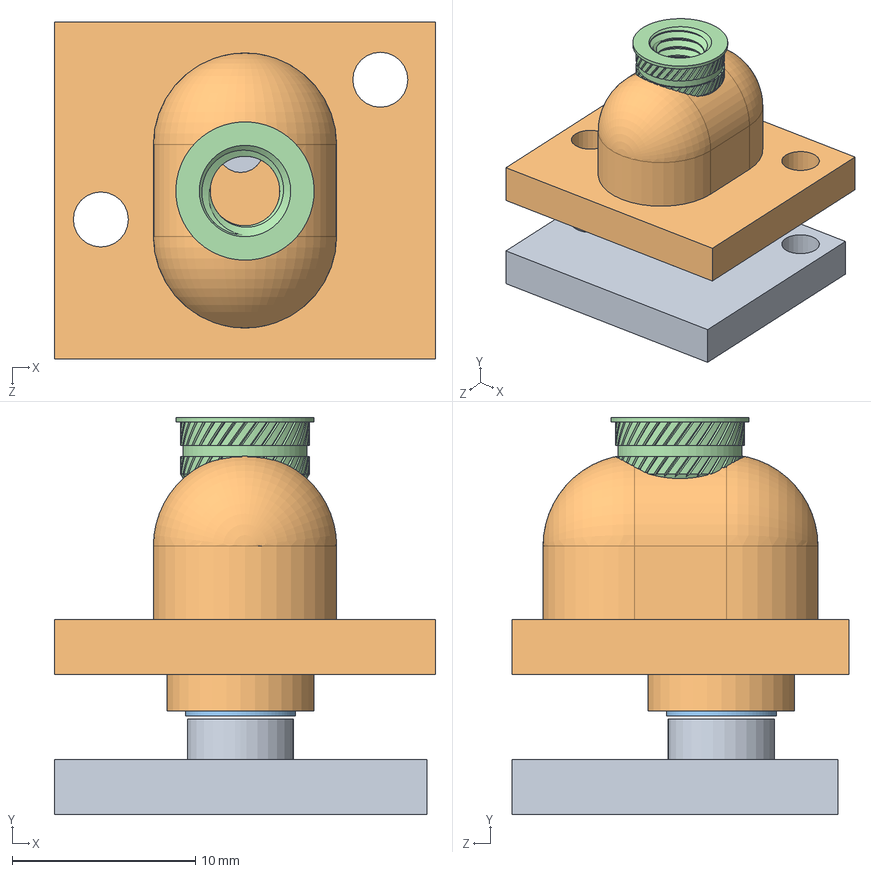
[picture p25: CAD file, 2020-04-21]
designs/Pressure transducer /ForceSensorAssem.SLDASM
20.8 x 21.6 x 18.4 mm
PressureSensor
Capsulev1
1171N116_SQUARE-PROFILE O-RING
93365A240_HEAT-SET INSERTS FOR PLASTICS

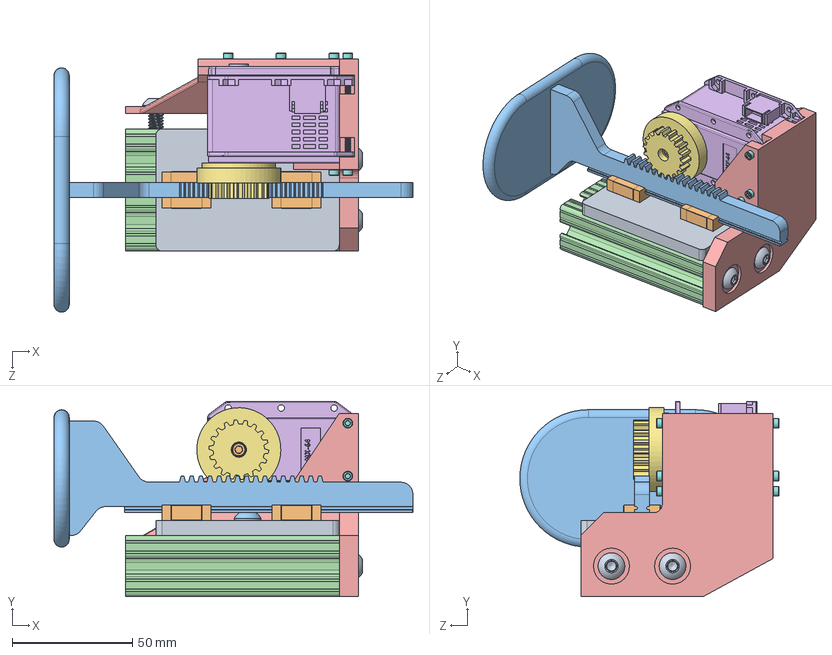
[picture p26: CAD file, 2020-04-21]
designs/Full System CAD/Current pump/piston assembly.SLDASM
149.2 x 81.2 x 107.8 mm
Acrylic topper
rack mount x 2
Pump piston rack
80_20 double 3.5in
Motor mount
MX-64 Motor (from grabacad)
Pump pinion
motor mount screw x 8
.25-20 extra screw x 4
pinion mounting screw
80_20 fastening screw

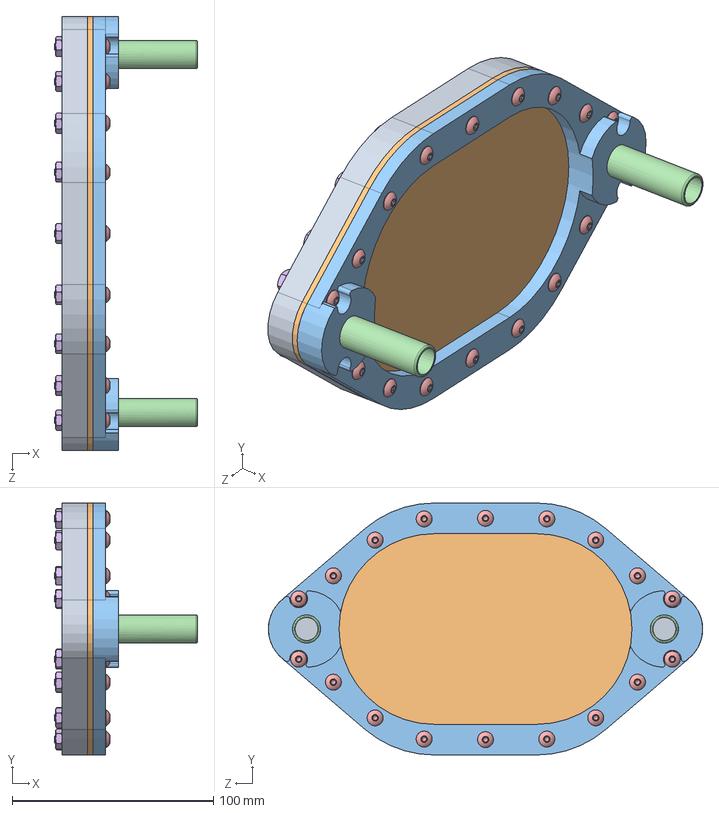
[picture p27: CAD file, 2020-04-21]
designs/Full System CAD/Current pump/membrane assembly.SLDASM
71.1 x 125.2 x 215.9 mm
Pump membrane backing
Pump membrane
Pump membrane front
Pump membrane fitting x 2
membrane screw x 18
membrane nut x 18

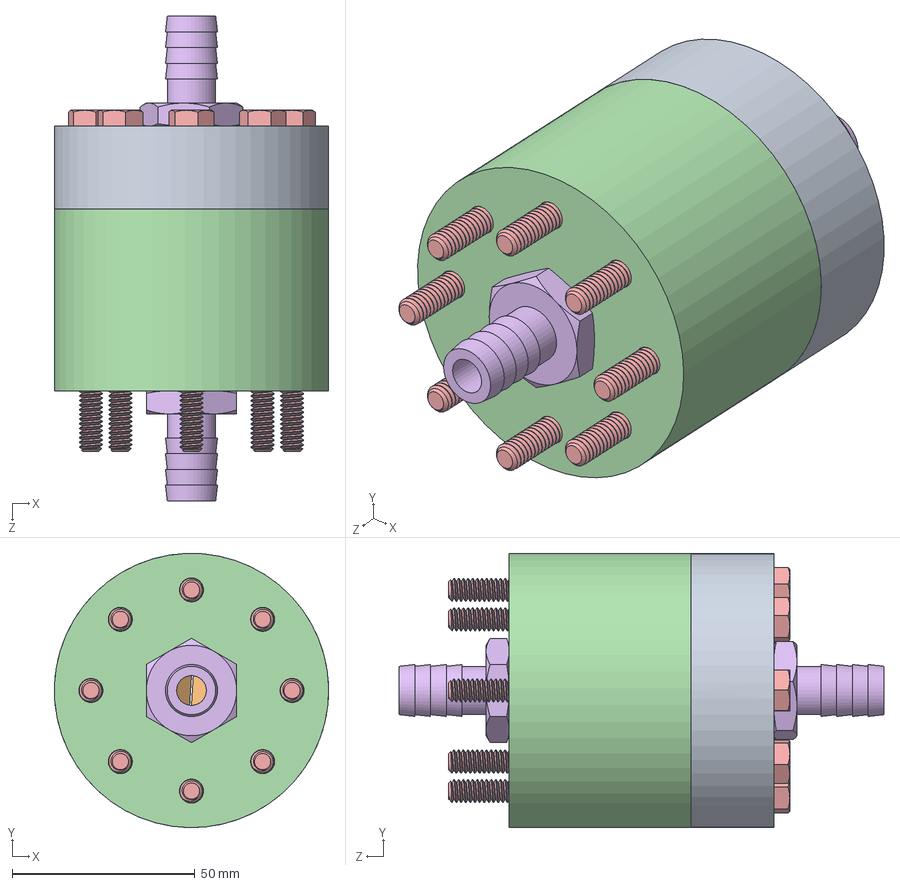
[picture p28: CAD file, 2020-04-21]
designs/Full System CAD/Processing_chamber/Processing_chamber.SLDASM
75.0 x 75.0 x 132.6 mm
Bottom
Heart_Valve
o-ring
Top_V2
91257A556_HIGH-STRENGTH GRADE 8 STEEL CAP SCREW x 8
half NPT to half in tube x 2

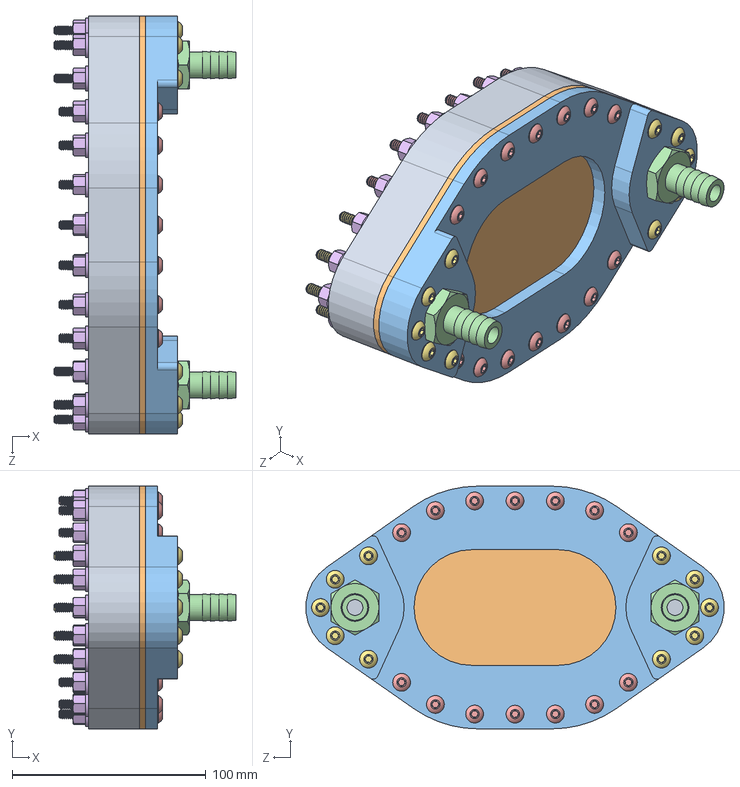
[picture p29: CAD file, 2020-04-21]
designs/Full System CAD/Pump redesign concept/redesigned pump membrane assembly.SLDASM
93.6 x 125.2 x 215.6 mm
redesigned pump membrane backing
redesigned pump membrane
redesigned membrane front
half NPT to half in tube x 2
91255A252_membrane screw x 14
membrane nut 10_24 x 24
91255A813_membrane screw long x 10

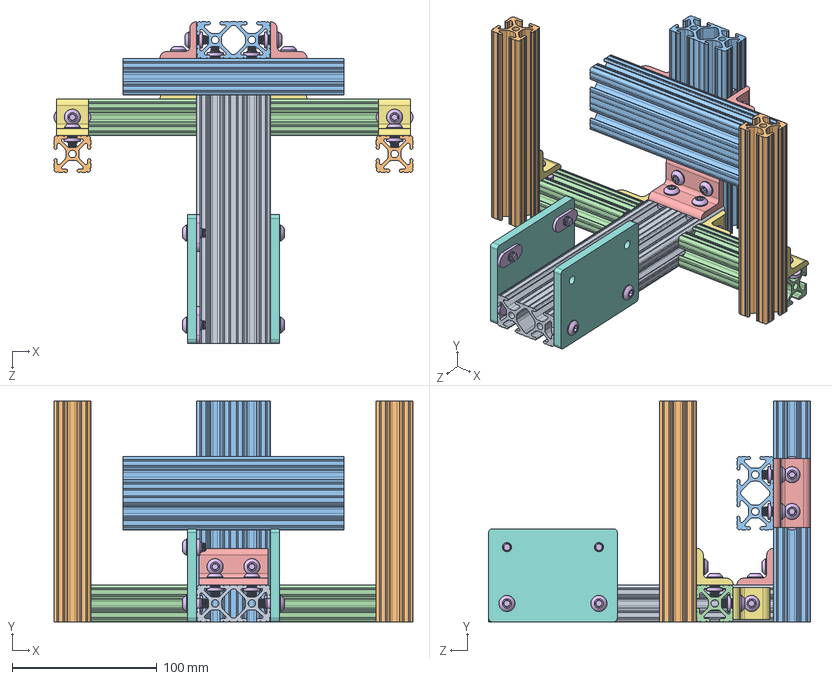
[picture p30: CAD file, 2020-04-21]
designs/Full System CAD/Frame/Membrane Mount.SLDASM
247.9 x 152.4 x 222.2 mm
47065T418_ALUMINUM T-SLOTTED FRAMING EXTRUSION
80_20 6in x 2
80_20 double 6in x 2
80_20 3.75in x 2
80_20 L bracket wide x 3
80_20 fastening screw x 26
80_20 L-bracket small x 4
pump acrylic aligner x 2

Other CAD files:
designs/Back Pressure/Solidworks/Main body.SLDPRT
designs/Full System CAD/Compliance Chamber/CAD/FINAL DESIGN/Main body.SLDPRT
designs/Back Pressure/Solidworks/Bottom cap.SLDPRT
designs/Back Pressure/Solidworks/Compliance chamber assembly.SLDDRW
designs/Back Pressure/Solidworks/Flange.SLDDRW
designs/Back Pressure/Solidworks/Flange.SLDPRT
designs/Back Pressure/Solidworks/McMaster O-RING #254.SLDPRT
designs/Back Pressure/Solidworks/Top Cap.SLDPRT
designs/Extra fittings/4880K343_1-2NPTmale-to-1-4NPTfemale.SLDPRT
designs/Extra fittings/51525K286_female luer to 1-4 barb.SLDPRT
designs/Extra fittings/51525K437_1-4NPT-to-Luer.SLDPRT
designs/Extra fittings/9198T16(NOT USED)_luer male to 1-4 barb with shut off valve.SLDPRT
designs/Extra fittings/9198T18(NOT USED)_1-4NPT to Luer Female with Shut off valve.SLDPRT
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

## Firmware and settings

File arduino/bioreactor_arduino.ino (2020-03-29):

#include "Dynamixel_Serial.h"       // Library needed to control Dynamixal servo
#include "SparkFun_MS5803_I2C.h"
#include <Wire.h>

// ID of Dynamixel Servo
#define SERVO_ID 0x01

// Create MS5803 pressure sensor objects (sensors before and after heart valve)
MS5803 sensor_p1(ADDRESS_HIGH);
MS5803 sensor_p2(ADDRESS_LOW);

// Use Arduino's setup() function to run code before continous loop
void setup(){
    // Give time for Dynamixel servo motor to start on power-up
    delay(1000);

    // Begin Dynamixel servo motor with specified baudrate and control pin on hardware
    Dynamixel.begin(1000000,0x02);

    // Visually show that Dynamixel servo is communicating with Arduino via its LED light
    Dynamixel.ledState(SERVO_ID, ON);
    delay(5);

    // Set Dynamixel servo motor's mode to SERVO (ie. control angular position and not rotational velocity)
    Dynamixel.setMode(SERVO_ID, SERVO,0x000,0xFFF);
    delay(5);

    // Start the I2C communication ports on the Arduino (used by the MS5803 sensors)
    Wire.begin();

    // Reset and begin each sensor
    sensor_p1.reset();
    sensor_p2.reset();
    sensor_p1.begin();
    sensor_p2.begin();

    // Begin Arduino serial port at chosen baud rate
    Serial.begin(1000000);
}

// Infinite loop that will run continuously on the Arduino after setup() runs once
int start_time = 0;
void loop(){
    // Digital pin used for toggle switch
    int digitalIn = 4;

    // Value for writing the servo's position
    int servo_write = 0;

    // Value for storing time in milliseconds
    int time_ms = 0;

    // Record sensor pressure at highest resolution
    double pressure_abs_p1 = sensor_p1.getPressure(ADC_4096);
    double pressure_abs_p2 = sensor_p2.getPressure(ADC_4096);

    // Using toggle switch to allow servo to actuate or stay in rest position
    if (digitalRead(digitalIn) == LOW) {
        // If toggle switch is off, set servo to rest position and hold
        Dynamixel.servo(SERVO_ID,1200,0x3FF);

        // Continuously updating start time so that when toggle switch is flipped
        // the time elapsed since the servo command was first issued is accurate
        start_time = (int) millis();

    } else {
        // Servo movement is a time-dependent linear function following the generic (y = mx + b) equation
        // Start and stop positions for linear movement
        int start_pos = 1200;
        int stop_pos = 700;

        // Slope of curve determines duration of movement (slope=1000 means 1200->700 in 0.5sec)
        int slope = 2000;
        time_ms = ((int) millis()) - start_time;
        servo_write = (-slope * (time_ms / 1000.0)) + start_pos;

        // Saturate servo movement between start and stop positions
        servo_write = max(min(servo_write, start_pos), stop_pos);

        // Move the servo motor with speed set to max servo speed
        Dynamixel.servo(SERVO_ID,servo_write,0x3FF);
    
        // Move servo back once goal position reached hit to create sinusoidal movement in and out
        if (servo_write == stop_pos) {

            // Restart timers
            time_ms = 0;
            start_time = (int) millis();

            // Move the servo linearly back to the start position
            while (servo_write < start_pos) {
                // Get current time
                time_ms = ((int) millis()) - start_time;

                // Command servo following same equation as before but with positive slope
                servo_write = (slope * (time_ms / 1000.0)) + stop_pos;
                servo_write = max(min(servo_write, start_pos), stop_pos);
                Dynamixel.servo(SERVO_ID,servo_write,0x3FF);

                // Record data during this while loop and print to serial port
                pressure_abs_p1 = sensor_p1.getPressure(ADC_4096);
                pressure_abs_p2 = sensor_p2.getPressure(ADC_4096);
                Serial.print(time_ms);
                Serial.print(", ");
                Serial.print(servo_write);
                Serial.print(", ");
                Serial.print(pressure_abs_p1);
                Serial.print(", ");
                Serial.print(pressure_abs_p2);
                Serial.print(", ");
                Serial.print("\n");
            }

            // Restart start timer after start position is reached
            start_time = (int) millis();
        }
    }

    // Record data and print to serial port for data acquisition
    // technically there is latency between these variable measurements but for the time resolution needed
    // for this project this is okay
    Serial.print(time_ms);
    Serial.print(", ");
    Serial.print(servo_write);
    Serial.print(", ");
    Serial.print(pressure_abs_p1);
    Serial.print(", ");
    Serial.print(pressure_abs_p2);
    Serial.print(", ");
    Serial.print("\n");
}

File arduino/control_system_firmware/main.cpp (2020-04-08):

//
// Created by lutkus on 2/7/20.
//
#include "bioreactor_firmware.h"
#include <iostream>

int main() {

    // Initialize PID controller and tune it
    PID pid("PID Example");
    float PID_values[3] = {1, 0.2, 0.2};
    pid.tune_controller(PID_values);

    // Setup data logger
    std::string filename = "my_file_test.csv";
    int num_outputs = 3;
    DataLogger datalogger(filename, num_outputs);

    // Create test data of "system state"
    float test_data[5] = {1, 2, 3, 4, 5};

    // Reset integral and error of PID
    pid.reset_integral();
    pid.reset_error();

    // Loop over data, performing control action and saving output
    for (int i = 0; i < 5; i++) {
        float pid_output = pid.control_action(test_data[i], 3, 0.1);
        std::cout << "Desired State: " << 5 << " Current State: " << test_data[i] << " PID Output: " << pid_output << std::endl;
        float data[3] = {5, test_data[i], pid_output};

        datalogger.save_data(data);
    }
    return 0;
}

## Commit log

2020-01-13 Sample actual pressure waveform included in test
2020-01-13 Working through ways to handle lab user data
    [lab_user_settings.xlsx]
2020-01-18 finished lab_user_data excel sheet and pulling into gui
    [lab_user_settings.xlsx]
2020-01-29 Renamed folder to gui
    [lab_user_settings.xlsx]
2020-01-29 Further restructuring, separating gui sensors and pump into respective folders
    [lab_user_settings.xlsx]
2020-02-07 Added firmware folder, parent class files, and external libs for pump motor and pressure sensors
2020-02-08 Finished Sensor parent, working on MS5803 child
2020-02-17 Added temporary quick script for using pump and sensors before firmware is ready
2020-02-18 Collected initial data on pump
    [first_data.csv, piston_bladder_test1.csv, piston_bladder_test2.csv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]
2020-02-21 Reorganizing to 2 cpp/hpp files because arduino is dumby dumb with dependencies
2020-02-29 Started Datalogger implementation
    [first_data.csv]
2020-03-01 Finished DataLogger
    [my_file_test.csv]
2020-03-06 Performed bladder experiments
    [bladder_constant_experiment.csv, piston_bladder_test1.csv, piston_bladder_test2.csv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]
2020-03-06 Started Matlab<-Arduino interface
    [lab_user_settings.xlsx]
2020-03-14 Updates to gui and implemented arduino mega script
2020-03-17 More data collection
    [120_bpm_p1.csv, 120_bpm_p2.csv, 30_bpm_holdpaddlein.csv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]
2020-03-20 Relocated data and cleaned up servo_move
    [120_bpm_p1.csv, 120_bpm_p2.csv, 30_bpm_holdpaddlein.csv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]
2020-03-21 Moved libraries into same directory as servo move folder
2020-04-02 Cleaning repo before giving access to group
    [bladder_constant_experiment.csv, my_file_test.csv, piston_bladder_test1.csv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]
2020-04-21 Added CAD to repo
    [.25-20 extra screw.SLDPRT, .5in tubing to .5in tubing to male luer tee fitting.SLDPRT, 1171N116_SQUARE-PROFILE O-RING.SLDPRT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]
